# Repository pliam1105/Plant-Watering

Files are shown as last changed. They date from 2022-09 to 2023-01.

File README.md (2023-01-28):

# Plant Watering
## Overview
A system that can be used to remotely check the watering status of some plants. The system is being currently used for some plants of my family, one hour away from our home: [Website](http://pliamprojects.000webhostapp.com/plants/)

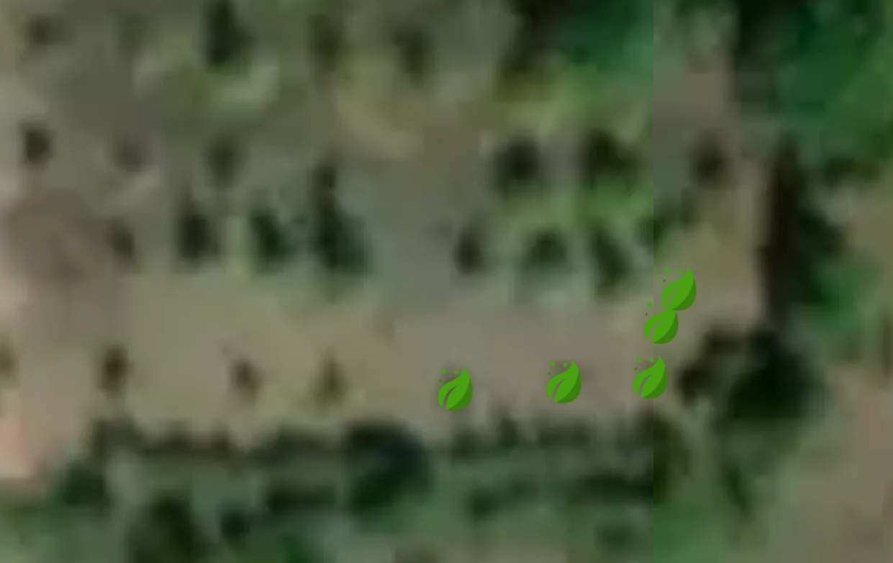
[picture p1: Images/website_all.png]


## Hardware

The main components used for this project are:
* ESP32 DevKit V1 (because I first tested the system with Wi-Fi)
* SIM800L GSM Module
* Soil Moisture Sensors and Hygrometer Modules

The (5 at the time) sensors are connected to the same ESP32 module (via long wires), which is the one that sends the data to a database<br>
The solar-powering system consists of the following:
* 2x Li-Ion 18650 Batteries
* 5V 0.5W Solar panel
* 2x 18650 3200mAh 3.6V Li-Ion batteries
* TP2056 Li-Ion battery charging module that is connected to the solar panel and the battery
* 5v USB booster converter module
* A MOSFET that controls the power of the sensors and the GSM module
* 220uF capacitor to achieve the 2A surge current needed by the GSM module

The connections are depicted on the following circuit:

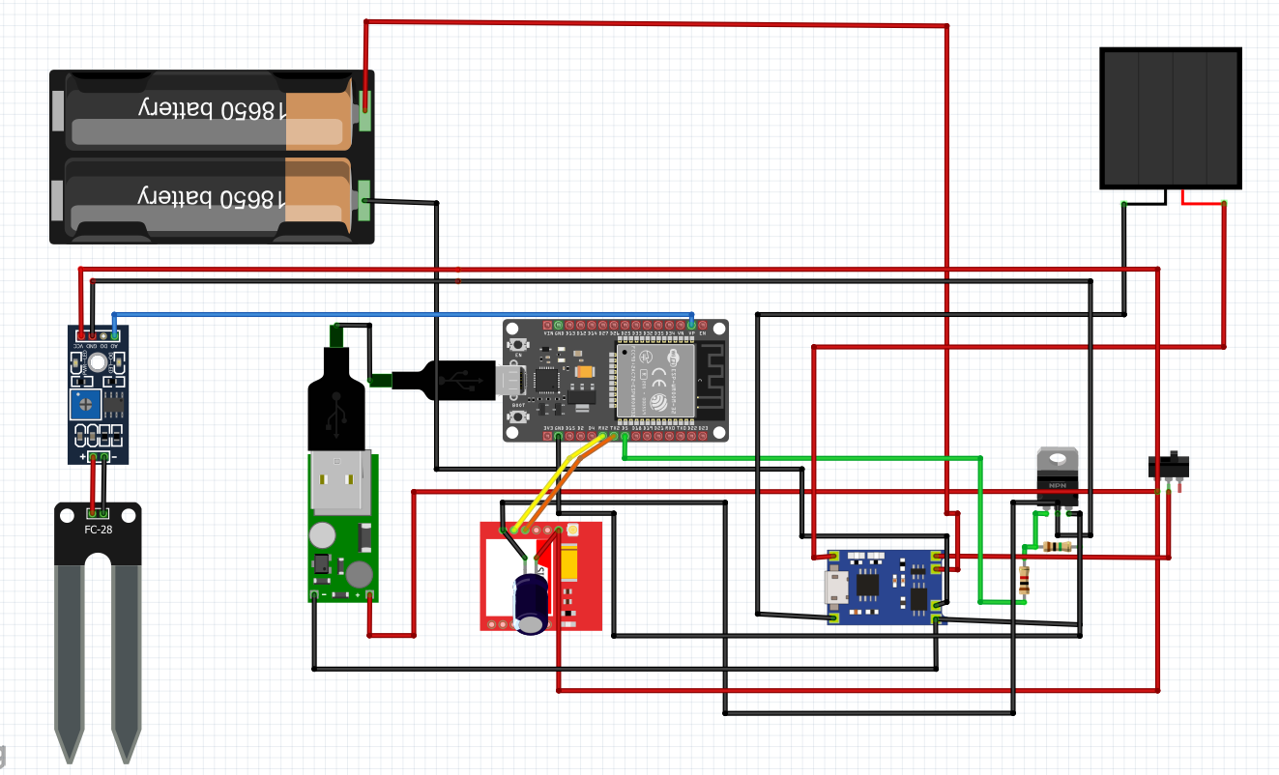
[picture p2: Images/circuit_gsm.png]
Circuit


## Software/Control

The ESP-32 gets the values from the sensors (the average of 500 fast consecutive measurements to eliminate errors) and sends them to an online database using some [PHP files](Website/post_moisture_esp.php).

[Arduino Code](Arduino/Moisture_Control_GSM/Moisture_Control_GSM.ino)

Because because power consumption was a main concern, I used the sleep mode of ESP32 and set it so that it sleeps for 12 hours after sending data.<br>
As the field where I wanted to install the sensors is in a remote area where there isn’t some Wi-Fi source near it, I concluded that I should use a GSM module directly connected to the ESP-32, as well as a MOSFET that could turn it off when not needed. I also used this MOSFET to switch the power of the sensors on and off when the ESP-32 is in sleep mode.

## Database

The data of the sensors are stored in a database, as shown below:


## Website ([Link](http://pliamprojects.000webhostapp.com/plants/))

The website with which I check the watering of the plants contains a map with some markers, that correspond to the sensors and show the value of the sensor and the watering status represented with colors and “Watered” or “Dry”.

[Website Code](Website/index.php)

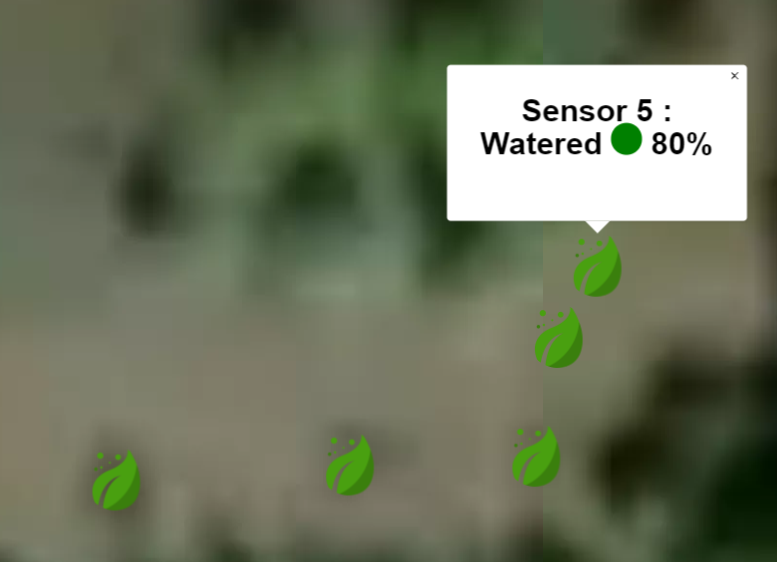
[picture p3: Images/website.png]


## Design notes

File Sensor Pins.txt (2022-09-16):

//sensor pins
const int pin_1 = 36;//ADC1
const int pin_2 = 39;
const int pin_3 = 32;
const int pin_4 = 33;
const int pin_5 = 34;
const int pin_6 = 35;

const int pin_7 = 4;//ADC2
const int pin_8 = 26;
const int pin_9 = 2;
const int pin_10 = 15;
const int pin_11 = 13;
const int pin_12 = 12;
const int pin_13 = 14;
const int pin_14 = 27;
const int pin_15 = 25;

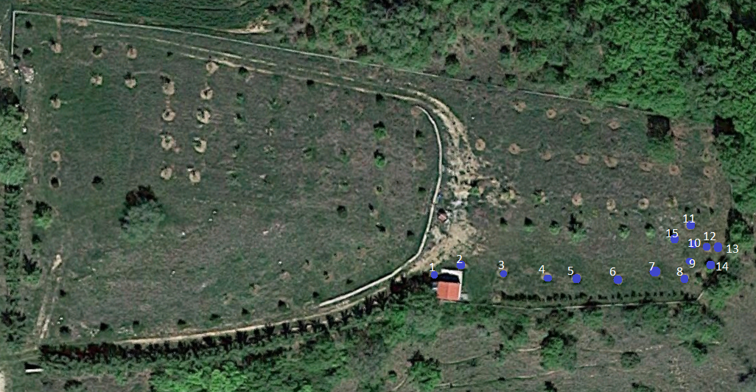
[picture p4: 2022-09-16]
Plants View.PNG

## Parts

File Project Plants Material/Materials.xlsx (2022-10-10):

Name | Code | Supplier | Price | Link
CAPACITIVE SOIL MOISTURE SENSOR MODULE FOR ARDUINO | 1140.928 | cableworks.gr | 4.80 € | https://www.cableworks.gr/ilektronika/arduino-and-microcontrollers/mcu-and-components/temperature/capacitive-soil-moisture-sensor-module-for-arduino/
TP4056 18650 5V MICRO USB CHARGER MODULE WITH CHARGE PROTECTION | 1116.336 | cableworks.gr | 1.12 € | https://www.cableworks.gr/ilektronika/arduino-and-microcontrollers/modules/charging/tp4056-18650-5v-micro-usb-charger-module-with-charge-protection/
1N4007 DO-41 RECTIFIER DIODE 1A 1000V | 1215.396 | cableworks.gr | 0.05 € | https://www.cableworks.gr/ilektronika/arduino-and-microcontrollers/components-and-ic/1n4007-do-41-rectifier-diode-1a-1000v/
5V 0.5W MINI SOLAR PANEL 100X50MM | 1215.221 | cableworks.gr | 3.50 € | https://www.cableworks.gr/ilektronika/arduino-and-microcontrollers/modules/solar/5v-0.5w-mini-solar-panel-100x50mm
DC-DC 0.9V-5V TO 5V 600MA VOLTAGE USB BOOST CONVERTER MODULE | 1116.092 | cableworks.gr | 1.30 € | https://www.cableworks.gr/ilektronika/arduino-and-microcontrollers/buck-and-boost-converters/boost-converter-step-up-dc-dc/dc-dc-0.9v-5v-to-5v-600ma-voltage-u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
Samsung ICR 18650-22P 2200mAh 3.6V | PRD-001143 | devobox.com | 3.50 € | https://www.devobox.com/el/18650/411-samsung-icr-18650-22p-2200mah-36v.html
1x18650 Battery holder without DC connector | 070.0059 | hellasdigital.gr | 0.79 € | https://www.hellasdigital.gr/electronics/prototyping/cases/1x18650-battery-holder-without-dc-connector/
Overall: |  |  | 15.06 €

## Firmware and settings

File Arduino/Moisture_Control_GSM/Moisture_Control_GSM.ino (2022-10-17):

// Configure TinyGSM library
#define TINY_GSM_MODEM_SIM800
//#define TINY_GSM_RX_BUFFER   1024
#include <TinyGsmClient.h>

// Set serial for debug console (to Serial Monitor, default speed 115200)
#define SerialMon Serial

HardwareSerial SerialAT(1);
TinyGsm modem(SerialAT);
TinyGsmClient client(modem);
const int BAUD_RATE = 9600;
const int RX_PIN = 16, TX_PIN = 17;

// Your GPRS credentials (leave empty, if not needed)
const char apn[]      = "internet"; // APN (example: internet.vodafone.pt) use https://wiki.apnchanger.org
const char gprsUser[] = ""; // GPRS User
const char gprsPass[] = ""; // GPRS Password

// SIM card PIN (leave empty, if not defined)
const char simPIN[]   = ""; 

// Server details
const char server[] = "pliamprojects.000webhostapp.com";
const char resource[] = "/plants/post_moisture_esp.php";
const int  port = 80;

const int pin_transistor = 5;

//sensor pins
const int pin_1 = 36;//ADC1
const int pin_2 = 39;
const int pin_3 = 32;
const int pin_4 = 33;
const int pin_5 = 34;
const int pin_6 = 35;

const int pin_7 = 4;//ADC2
const int pin_8 = 26;
const int pin_9 = 2;
const int pin_10 = 15;
const int pin_11 = 13;
const int pin_12 = 12;
const int pin_13 = 14;
const int pin_14 = 27;
const int pin_15 = 25;

//sensor values
int val_1 = 0;
int val_2 = 0;
int val_3 = 0;
int val_4 = 0;
int val_5 = 0;
int val_6 = 0;
int val_7 = 0;
int val_8 = 0;
int val_9 = 0;
int val_10 = 0;
int val_11 = 0;
int val_12 = 0;
int val_13 = 0;
int val_14 = 0;
int val_15 = 0;

//value range
const int dry = 4095;
const int wet = 2600;

//php auth code
String api_key = "tk647vDfs2Kes";

//sleep variables
uint64_t big_sleep = 12;
uint64_t hours_m_seconds = 3600000000;

void setup() {
  pinMode(pin_transistor,OUTPUT);
  digitalWrite(pin_transistor,HIGH);
  Serial.begin(115200);
  Serial.println("Woke Up!");
  read_sensors();
  //initialize SIM800L
  // Unlock your SIM card with a PIN if needed
  if (strlen(simPIN) && modem.getSimStatus() != 3 ) {
    modem.simUnlock(simPIN);
  }
  SerialAT.begin(BAUD_RATE, SERIAL_8N1, RX_PIN, TX_PIN, false);
  delay(3000);
  SerialMon.println("Initializing modem...");
  modem.restart();
}

void loop() {
  digitalWrite(pin_transistor,LOW);
  delay(3000);
  digitalWrite(pin_transistor,HIGH);
  SerialMon.print("Connecting to APN: ");
  SerialMon.print(apn);
  if (!modem.gprsConnect(apn, gprsUser, gprsPass)) {
    SerialMon.println(" fail");
  }
  else {
    SerialMon.println(" OK");
    
    SerialMon.print("Connecting to ");
    SerialMon.print(server);
    if (!client.connect(server, port)) {
      SerialMon.println(" fail");
    }
    else {
      SerialMon.println(" OK");
    
      // Making an HTTP POST request
      SerialMon.println("Performing HTTP POST request...");
      // Prepare HTTP POST request data
      String httpRequestData = "api_key=" + api_key + "&sensor1=" + val_1
    + "&sensor2=" + val_2
    + "&sensor3=" + val_3
    + "&sensor4=" + val_4
    + "&sensor5=" + val_5
    + "&sensor6=" + val_6
    + "&sensor7=" + val_7
    + "&sensor8=" + val_8
    + "&sensor9=" + val_9
    + "&sensor10=" + val_10
    + "&sensor11=" + val_11
    + "&sensor12=" + val_12
    + "&sensor13=" + val_13
    + "&sensor14=" + val_14
    + "&sensor15=" + val_15 + "";
    
      client.print(String("POST ") + resource + " HTTP/1.1\r\n");
      client.print(String("Host: ") + server + "\r\n");
      client.println("Connection: close");
      client.println("Content-Type: application/x-www-form-urlencoded");
      client.print("Content-Length: ");
      client.println(httpRequestData.length());
      client.println();
      client.println(httpRequestData);

      unsigned long timeout = millis();
      while (client.connected() && millis() - timeout < 10000L) {
        // Print available data (HTTP response from server)
        while (client.available()) {
          char c = client.read();
          SerialMon.print(c);
          timeout = millis();
        }
      }
      SerialMon.println();
    
      // Close client and disconnect
      client.stop();
      SerialMon.println(F("Server disconnected"));
      modem.gprsDisconnect();
      SerialMon.println(F("GPRS disconnected"));
      if(true){//check response and sleep
        uint64_t sleep_time = big_sleep;
        Serial.println("Going to sleep for " + String(uint64_to_string(sleep_time)) + " hours!");
        //Deep sleep
        digitalWrite(pin_transistor,LOW);
        gpio_deep_sleep_hold_en();
        gpio_hold_en(GPIO_NUM_5);
        esp_sleep_enable_timer_wakeup(sleep_time * hours_m_seconds);
        esp_deep_sleep_start();
        gpio_hold_dis(GPIO_NUM_5);
      }

    }
  }
  //Check connection every 30 seconds
  delay(30000);
}

void read_sensors (){

  measure_values();
  val_1 = map(val_1, dry, wet, 0, 100);
  Serial.println("Sensor 1: " + String(val_1) + " %");
  val_2 = map(val_2, dry, wet, 0, 100);
  Serial.println("Sensor 2: " + String(val_2) + " %");
  val_3 = map(val_3, dry, wet, 0, 100);
  Serial.println("Sensor 3: " + String(val_3) + " %");
  val_4 = map(val_4, dry, wet, 0, 100);
  Serial.println("Sensor 4: " + String(val_4) + " %");
  val_5 = map(val_5, dry, wet, 0, 100);
  Serial.println("Sensor 5: " + String(val_5) + " %");
  val_6 = map(val_6, dry, wet, 0, 100);
  Serial.println("Sensor 6: " + String(val_6) + " %");
  val_7 = map(val_7, dry, wet, 0, 100);
  Serial.println("Sensor 7: " + String(val_7) + " %");
  val_8 = map(val_8, dry, wet, 0, 100);
  Serial.println("Sensor 8: " + String(val_8) + " %");
  val_9 = map(val_9, dry, wet, 0, 100);
  Serial.println("Sensor 9: " + String(val_9) + " %");
  val_10 = map(val_10, dry, wet, 0, 100);
  Serial.println("Sensor 10: " + String(val_10) + " %");
  val_11 = map(val_11, dry, wet, 0, 100);
  Serial.println("Sensor 11: " + String(val_11) + " %");
  val_12 = map(val_12, dry, wet, 0, 100);
  Serial.println("Sensor 12: " + String(val_12) + " %");
  val_13 = map(val_13, dry, wet, 0, 100);
  Serial.println("Sensor 13: " + String(val_13) + " %");
  val_14 = map(val_14, dry, wet, 0, 100);
  Serial.println("Sensor 14: " + String(val_14) + " %");
  val_15 = map(val_15, dry, wet, 0, 100);
  Serial.println("Sensor 15: " + String(val_15) + " %");
}

void measure_values(){
  val_1=val_2=val_3=val_4=val_5=val_6=val_7=val_8=val_9=val_10=val_11=val_12=val_13=val_14=val_15=0;
  const int num = 500;
  for(int i=0;i<num;i++){
    val_1+=analogRead(pin_1);
    val_2+=analogRead(pin_2);
    val_3+=analogRead(pin_3);
    val_4+=analogRead(pin_4);
    val_5+=analogRead(pin_5);
    val_6+=analogRead(pin_6);
    val_7+=analogRead(pin_7);
    val_8+=analogRead(pin_8);
    val_9+=analogRead(pin_9);
    val_10+=analogRead(pin_10);
    val_11+=analogRead(pin_11);
    val_12+=analogRead(pin_12);
    val_13+=analogRead(pin_13);
    val_14+=analogRead(pin_14);
    val_15+=analogRead(pin_15);
    delay(20);
  }
  val_1/=num;
  val_2/=num;
  val_3/=num;
  val_4/=num;
  val_5/=num;
  val_6/=num;
  val_7/=num;
  val_8/=num;
  val_9/=num;
  val_10/=num;
  val_11/=num;
  val_12/=num;
  val_13/=num;
  val_14/=num;
  val_15/=num;
}

char *uint64_to_string(uint64_t input)
{
    static char result[21] = "";
    // Clear result from any leftover digits from previous function call.
    memset(&result[0], 0, sizeof(result));
    // temp is used as a temporary result storage to prevent sprintf bugs.
    char temp[21] = "";
    char c;
    uint8_t base = 10;

    while (input) 
    {
        int num = input % base;
        input /= base;
        c = '0' + num;

        sprintf(temp, "%c%s", c, result);
        strcpy(result, temp);
    } 
    return result;
}

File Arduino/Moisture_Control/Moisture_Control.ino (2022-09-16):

#include <WiFi.h>
#include <HTTPClient.h>
#include <NTPClient.h>
#include <WiFiUdp.h>

//sensor pins
const int pin_1 = 36;//ADC1
const int pin_2 = 39;
const int pin_3 = 32;
const int pin_4 = 33;
const int pin_5 = 34;
const int pin_6 = 35;

const int pin_7 = 4;//ADC2
const int pin_8 = 26;
const int pin_9 = 2;
const int pin_10 = 15;
const int pin_11 = 13;
const int pin_12 = 12;
const int pin_13 = 14;
const int pin_14 = 27;
const int pin_15 = 25;

//sensor values
int val_1 = 0;
int val_2 = 0;
int val_3 = 0;
int val_4 = 0;
int val_5 = 0;
int val_6 = 0;
int val_7 = 0;
int val_8 = 0;
int val_9 = 0;
int val_10 = 0;
int val_11 = 0;
int val_12 = 0;
int val_13 = 0;
int val_14 = 0;
int val_15 = 0;

//value range
const int dry = 3700;
const int wet = 1900;

//php auth code
String api_key = "tk647vDfs2Kes";

//network credentials
const char* ssid     = "WIFI0";
const char* password = "p@$$w0rd";

//server credentials
const char* serverName = "http://pliamprojects.000webhostapp.com/plants/post_moisture_esp.php";

//sleep variables
uint64_t sleep_hours = 2;
uint64_t big_sleep = 14;
uint64_t hours_m_seconds = 3600000000;

// Variables to save date and time
String formattedDate;
String dayStamp;
String timeStamp;
int time_val;

void setup() {
  Serial.begin(115200);
  Serial.println("Woke Up!");
  read_sensors();
  WiFi.begin(ssid, password);
  Serial.println("Connecting");
  while(WiFi.status() != WL_CONNECTED) { 
    delay(500);
    Serial.print(".");
  }
  Serial.println("");
  Serial.print("Connected to WiFi network with IP Address: ");
  Serial.println(WiFi.localIP());
  
  get_time();
}

void reset_sensors() {
  //because on first measure values are not correct, but on the second are correct(on some pins of ADC2)
  map(analogRead(pin_1), dry, wet, 0, 100);
  delay(50);
  map(analogRead(pin_2), dry, wet, 0, 100);
  delay(50);
  map(analogRead(pin_3), dry, wet, 0, 100);
  delay(50);
  map(analogRead(pin_4), dry, wet, 0, 100);
  delay(50);
  map(analogRead(pin_5), dry, wet, 0, 100);
  delay(50);
  map(analogRead(pin_6), dry, wet, 0, 100);
  delay(50);
  map(analogRead(pin_7), dry, wet, 0, 100);
  delay(50);
  map(analogRead(pin_8), dry, wet, 0, 100);
  delay(50);
  map(analogRead(pin_9), dry, wet, 0, 100);
  delay(50);
  map(analogRead(pin_10), dry, wet, 0, 100);
  delay(50);
  map(analogRead(pin_11), dry, wet, 0, 100);
  delay(50);
  map(analogRead(pin_12), dry, wet, 0, 100);
  delay(50);
  map(analogRead(pin_13), dry, wet, 0, 100);
  delay(50);
  map(analogRead(pin_14), dry, wet, 0, 100);
  delay(50);
  map(analogRead(pin_15), dry, wet, 0, 100);

  delay(500);
}

void get_time(){
  
  // Define NTP Client to get time
  WiFiUDP ntpUDP;
  NTPClient timeClient(ntpUDP);

  // Initialize a NTPClient to get time
  timeClient.begin();
  // Set offset time in seconds to adjust for your timezone, for example:
  // GMT +1 = 3600
  // GMT +8 = 28800
  // GMT -1 = -3600
  // GMT 0 = 0
  timeClient.setTimeOffset(3*3600);
  
  while(!timeClient.update()) {
    timeClient.forceUpdate();
  }
  // The formattedDate comes with the following format:
  // 2018-05-28T16:00:13Z
  // We need to extract date and time
  formattedDate = timeClient.getFormattedDate();
  Serial.println(formattedDate);

  // Extract date
  int splitT = formattedDate.indexOf("T");
  dayStamp = formattedDate.substring(0, splitT);
  Serial.print("DATE: ");
  Serial.println(dayStamp);
  // Extract time
  timeStamp = formattedDate.substring(splitT+1, formattedDate.length()-1);
  Serial.print("HOUR: ");
  Serial.println(timeStamp);

  int splitTime = timeStamp.indexOf(":");
  time_val = timeStamp.substring(0,splitTime).toInt(); // get time as int
  
  delay(500);
}

void loop() {

  //Check WiFi connection status
  if(WiFi.status()== WL_CONNECTED){
    HTTPClient http;
    
    // Specify content-type header
    http.addHeader("Content-Type", "application/x-www-form-urlencoded");
    
    // Prepare your HTTP POST request data
    String httpRequestData = "api_key=" + api_key + "&sensor1=" + val_1
    + "&sensor2=" + val_2
    + "&sensor3=" + val_3
    + "&sensor4=" + val_4
    + "&sensor5=" + val_5
    + "&sensor6=" + val_6
    + "&sensor7=" + val_7
    + "&sensor8=" + val_8
    + "&sensor9=" + val_9
    + "&sensor10=" + val_10
    + "&sensor11=" + val_11
    + "&sensor12=" + val_12
    + "&sensor13=" + val_13
    + "&sensor14=" + val_14
    + "&sensor15=" + val_15 + "";
    Serial.print("httpRequestData: ");
    Serial.println(httpRequestData);

    String url = serverName + String("?") + httpRequestData;
    Serial.print("Request URL: ");
    Serial.println(url);
    
    // Send HTTP GET request
    http.begin(url);
    int httpResponseCode = http.GET();
    String response = "";
    if (httpResponseCode>0) {
      response = http.getString();
      
      Serial.print("HTTP Response code: ");
      Serial.println(httpResponseCode);
      Serial.print("Response: ");
      Serial.println(response);
    }
    else {
      Serial.print("Error code: ");
      Serial.println(httpResponseCode);
    }
    
    // Free resources
    http.end();

    //check response and sleep
    if(httpResponseCode == 200 && response == "New record created successfully"){
      //success
      uint64_t sleep_time = sleep_hours;
      if(time_val > 6 && time_val < 20){
        //big sleep
        big_sleep = 20 - time_val; // calculate sleep time
        sleep_time = big_sleep;
      }
      Serial.println("Going to sleep for " + String(uint64_to_string(sleep_time)) + " hours!");
      //Deep sleep
      esp_sleep_enable_timer_wakeup(sleep_time * hours_m_seconds);
      esp_deep_sleep_start();
    }
  }
  else {
    Serial.println("WiFi Disconnected");
  }
  //Check connection every 30 seconds
  delay(30000);  
  
}
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
